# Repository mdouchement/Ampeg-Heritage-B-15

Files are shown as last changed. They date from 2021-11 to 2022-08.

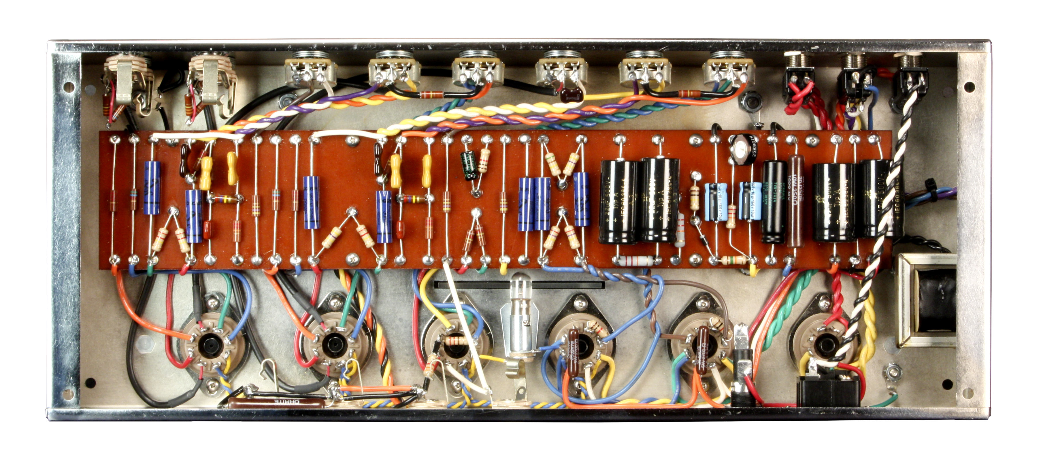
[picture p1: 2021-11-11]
Documents/_Wiring-official.jpg

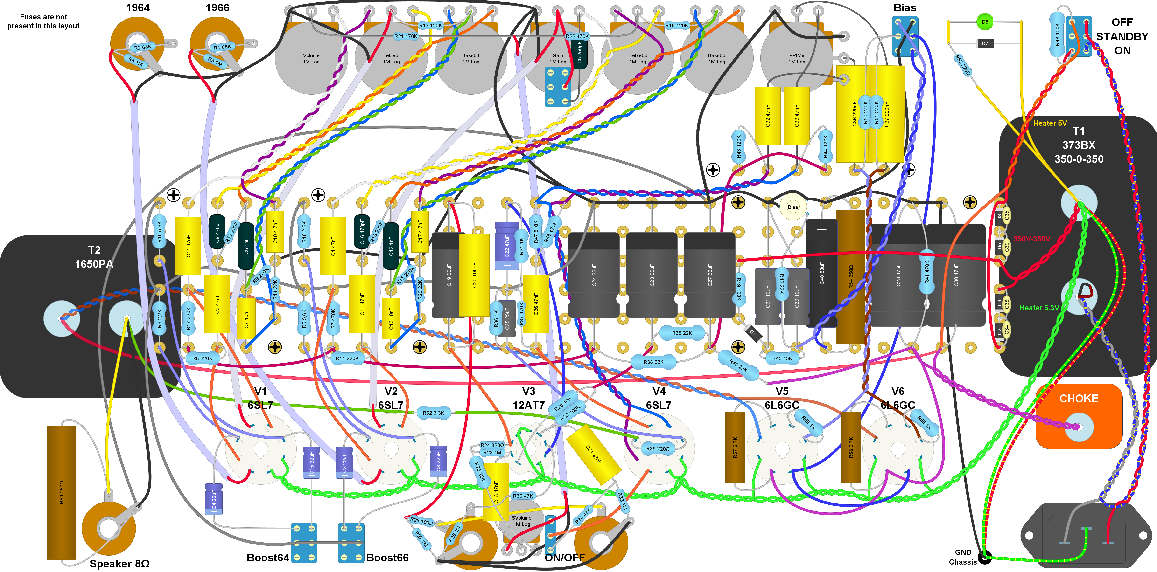
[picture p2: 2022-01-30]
HB15_layout.png

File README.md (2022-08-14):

# Ampeg HB15

This project is a custom modification of the original Ampeg Heritage B15.
You can download the schematic [HB15.pdf](HB15.pdf).

IMG_20220104_171503_nometa

## Warnings

- Use **6L6GC** valves that support 500V at the screen
- Always checks that all capacitors are discharged
  - Even if the 470k 2W resistor shoud discharged the capacitor

## Valves

Valves used in this project:
- TAD - 6L6GCM-STR REDBASE
- Philips USA as JAN 12AT7WC (6201) [NOS military grade]
- JAN 6SL7WGT Philips               [NOS military grade]
- Shuguang 6N9P J level             [NOS military grade]

## Custom mods

- The 100K 2W resistor in parallel with the standby switch reduce all the inrush current which is better for the capacitors
- Boost switches increase the gain of the triode by adding a bypass capactor
- Enable or disable the bright capacitor (boost in 8kHz)
- Effects Loop (buffered) is built to be transparent and you can do severals things around:
  - Enable or disable the effects loop
  - Can be used as a buffered preamp out
  - Can be used as an input for a "preamp in a box"
  - Can be used as distortion stage on the cathode follower by increasing the send volume
    - *Eventually a clean boost of the preamp*
- Post Phase Inverter Master Volume (PPIMV) allowing to push the preamp while keeping the amplifier not too loud
- Negative Feedback loop for rumble fix and different voicing (see schematic)
- Midranges boost is a custom version inpired from Pignose B100V amp
- Adding a 4.7nF capacitor in series with C1 and C3 to cut sub frequencies
  - It may be a side effect by replacing all 22nF by 47nF in order to support a 5 strings bass
  - It also due to the frequency response of my PF-210HE cabinet which have a greater low frequencies response
  - 3.3nF may be better depending your cabinet (and taste)

## Tips

- Use a rubber seal inside the chassis to easily mount a APEM 644 for example
- Use teflon tape and rubber seal to insulate metalic jack plug (e.g. Switchcraft 11) from the chassis to avoid ground loops
- Avoid soldering ground on the potentiometer's cover (gound loops enabler)

## Tools

- [KiCAD](https://kicad.org)
  - https://gitlab.com/kicad/code/kicad
  - https://github.com/KiCad
- [DIYLC](http://diy-fever.com/software/diylc)
  - https://github.com/bancika/diy-layout-creator
- [LiveSPICE](https://github.com/dsharlet/LiveSPICE)
- [Micro-Cap](http://www.spectrum-soft.com/index.shtm)

## Resources

- https://ampeg.com/support/files/Schematics/
- http://www.valvewizard.co.uk/index.html
- https://www.ampbooks.com/mobile/amplifier-calculators
- http://www.guitarscience.net/tsc/info.htm (tonestack calculator)
- https://trioda.com/tools/triode.html (Loadline calculator)

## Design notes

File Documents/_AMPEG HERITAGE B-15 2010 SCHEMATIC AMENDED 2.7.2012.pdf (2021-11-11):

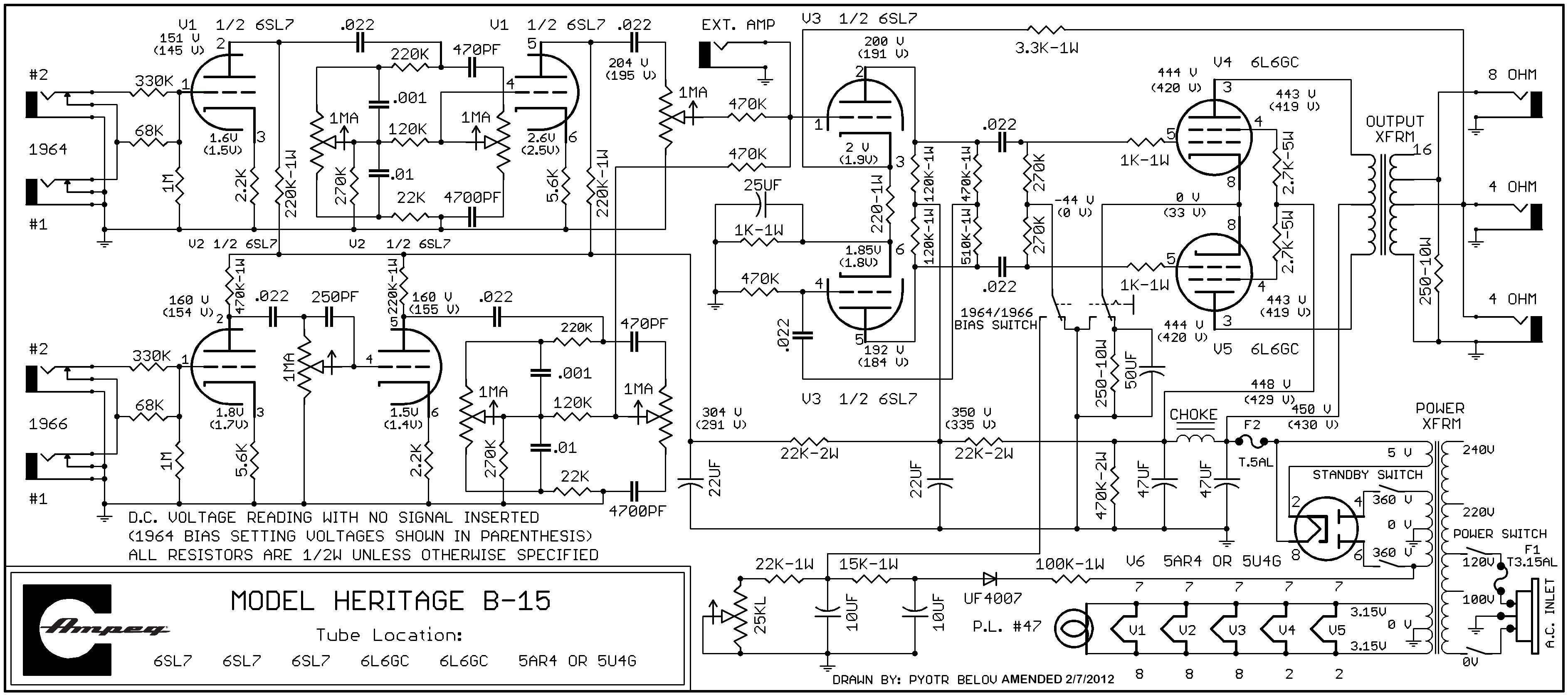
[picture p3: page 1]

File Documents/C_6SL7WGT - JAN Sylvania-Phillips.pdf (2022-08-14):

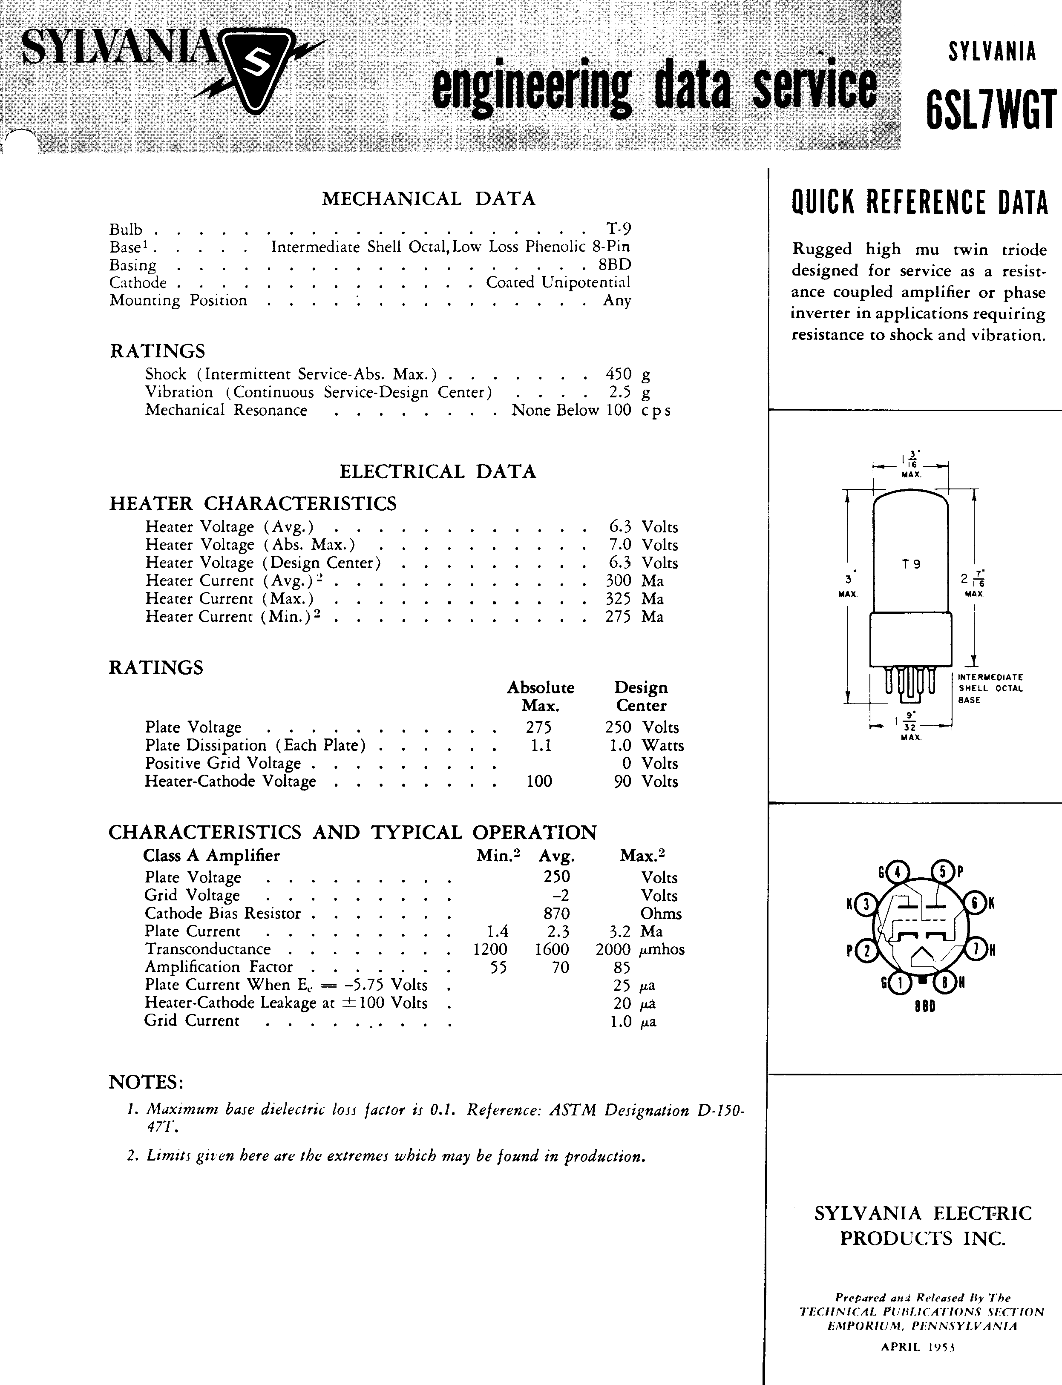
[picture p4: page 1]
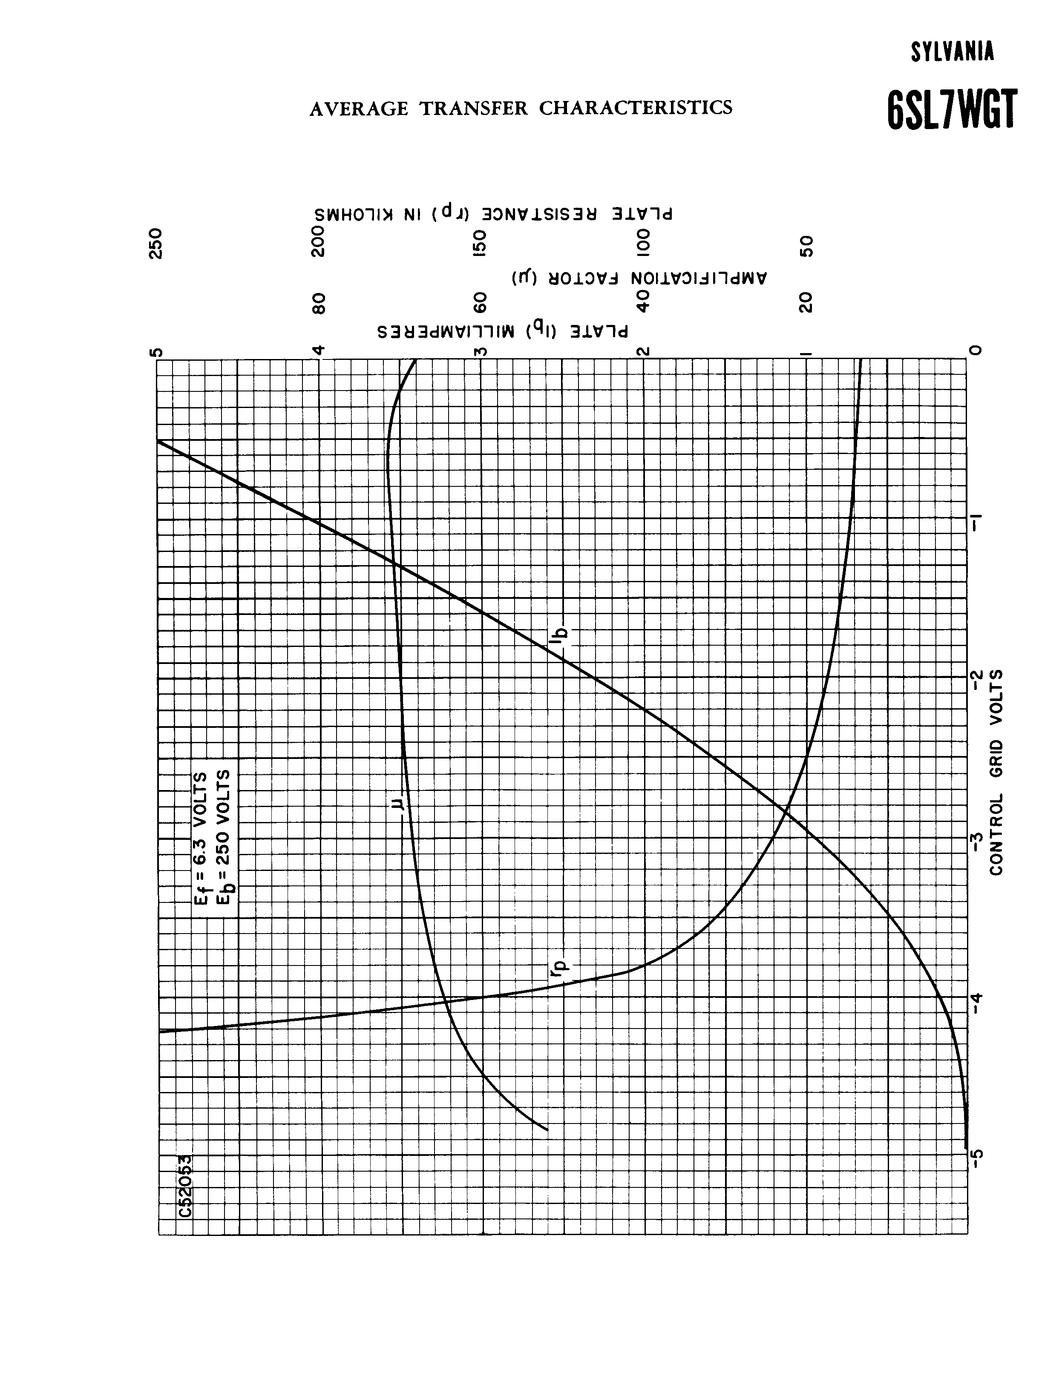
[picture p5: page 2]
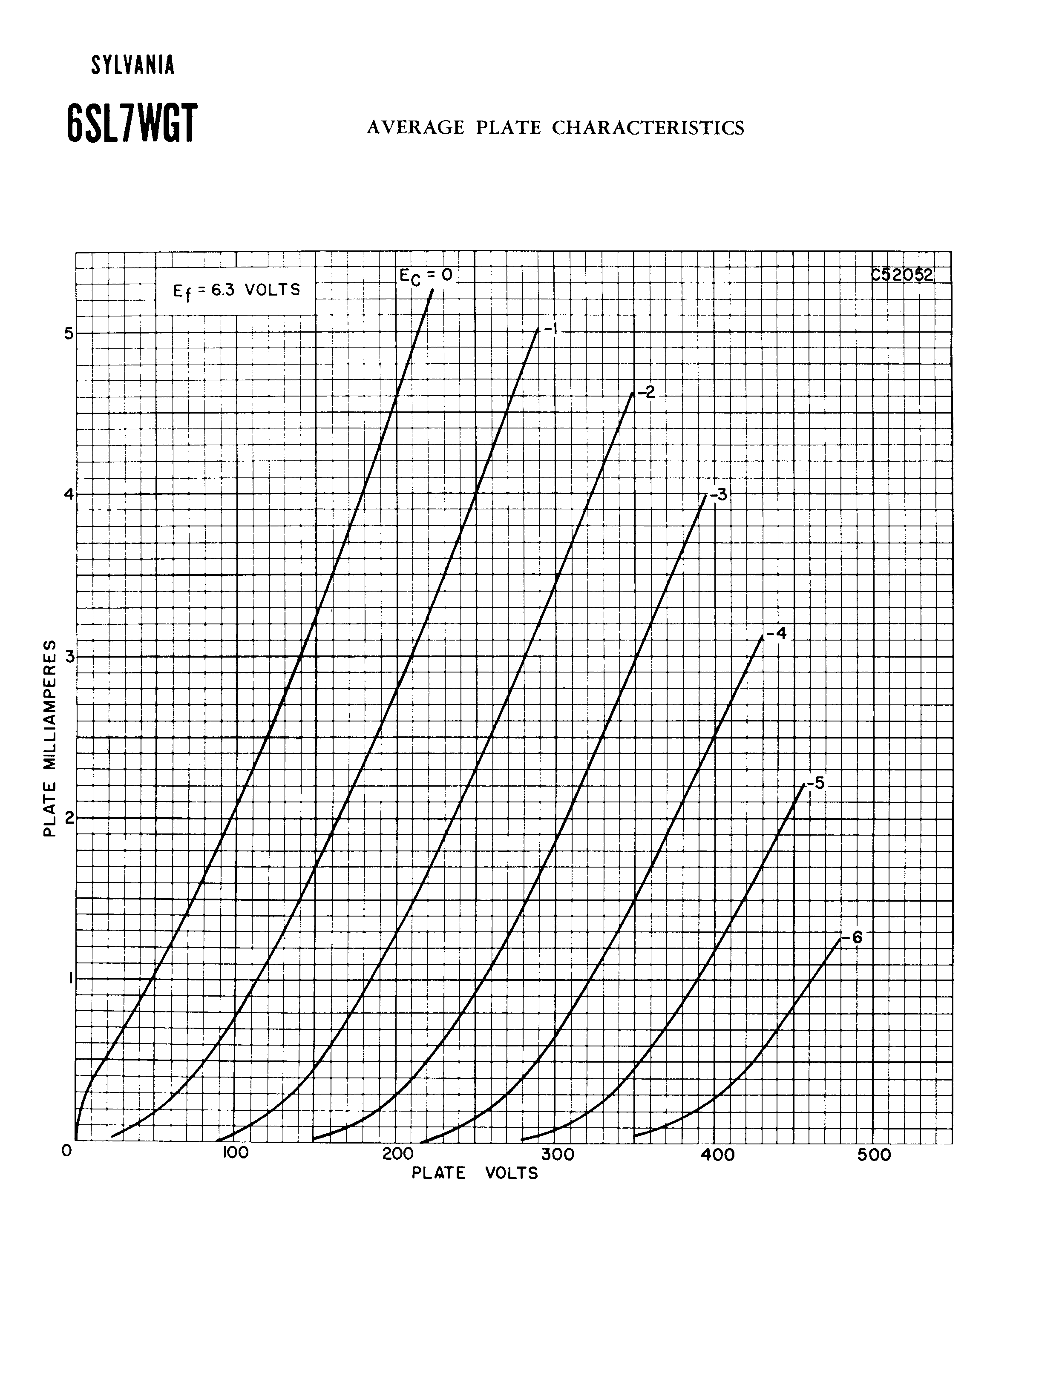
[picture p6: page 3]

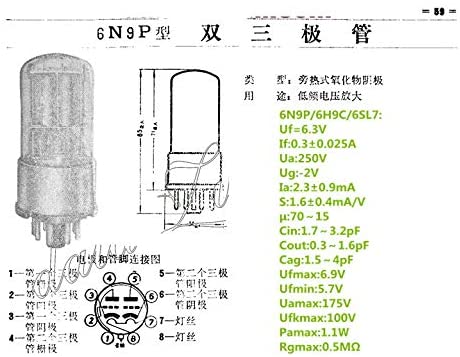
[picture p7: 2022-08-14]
Documents/C_6SL7 - 6N9P-1.jpg

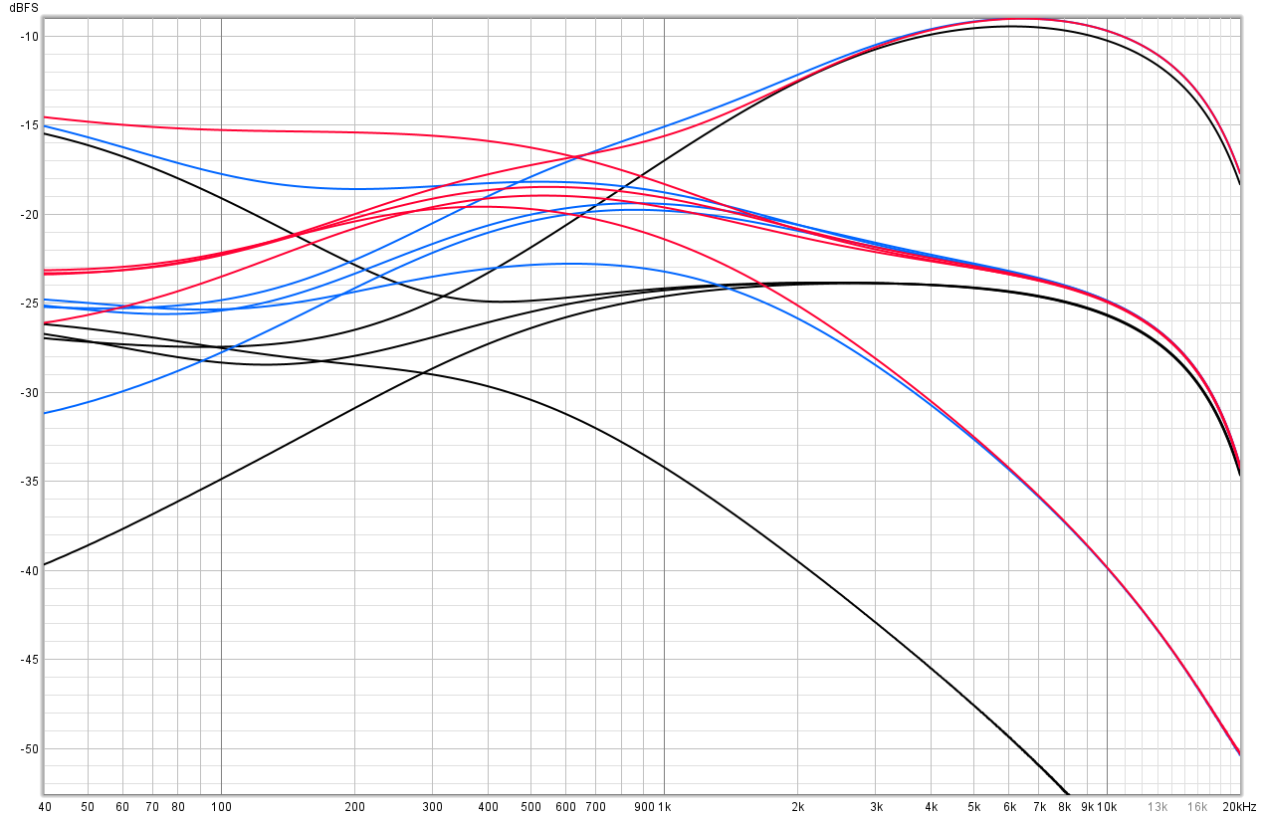
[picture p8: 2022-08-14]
Simulations/1.preamp.EQ.mods.pignose.png

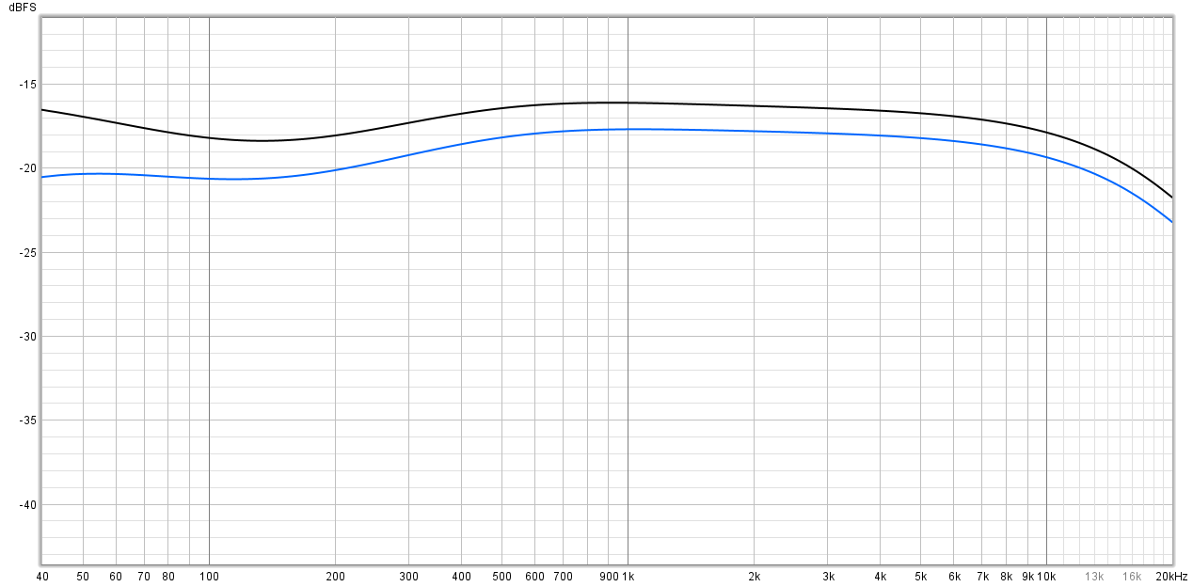
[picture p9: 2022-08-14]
Simulations/1.preamp.EQ.mods.sub_cut.png

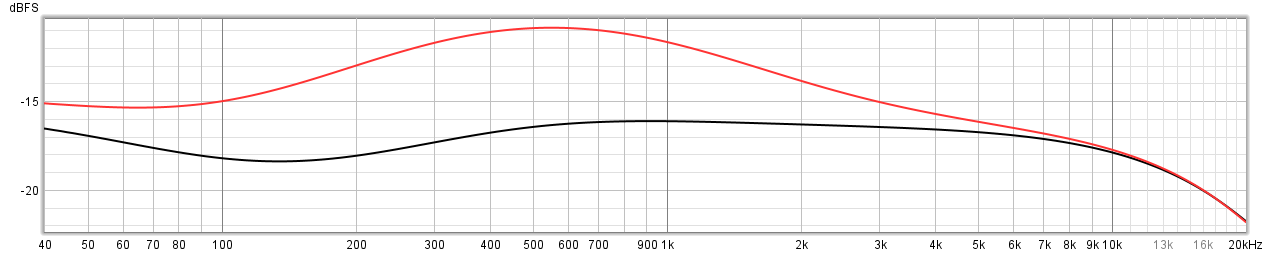
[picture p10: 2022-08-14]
Simulations/1.preamp.EQ.mods.pignose.mid_boost.png

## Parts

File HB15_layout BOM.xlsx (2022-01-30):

Name | Value | Quantity | Ref. | Dealers
Bass64, Bass66, Treble64, Treble66, Volume, SVolume | 1M Log | 5 | Alpha 16mm | Tube-Town | ok
PPIMV | 1M Log Stereo | 1 | Alpha Dual 16mm | Tube-Town | ok
Gain | 1M Log DPDT | 1 | Alpha Push-Pull 16mm | Tube-Town | ok
OFF-STANDBY-ON | DP3T | 1 | APEM 644 H/2 | Tube-Town | ok
Bias | DPDT | 1 | APEM 646 H/2 | Tube-Town | ok
ON/OFF effects loop | SPDT | 1 | Miyama MS-500B | Tube-Town | ok
Boost64, Boost66 | DPDT | 2 | Miyama MS500F | Tube-Town | ok
Bias | 25K Lin | 1 | Miniatur PT15 | Tube-Town | ok
C1, C3, C11, C14, C18, C21, C26, C32, C33 | 47nF 630V | 9 | Illinois Capacitor MPW | Tube-Town | ok
C2, C4, C8, C15 | 22uF 63V | 4 | Nichicon | Retroamplis
C5 | 250pF 500V | 1 | Silver Mica | Tube-Town | ok
C6, C12 | 1nF 500V | 2 | Silver Mica | Tube-Town | ok
C7, C13 | 10nF 630V | 2 | Illinois Capacitor MPW | Tube-Town | ok
C9, C16 | 470pF 500V | 2 | Silver Mica | Mouser
C10, C17 | 4,7nF 630V | 2 | Illinois Capacitor MPW | Tube-Town | ok
C19 | 22uF 350V | 1 | F&T | Tube-Town | ok
C23, C24, C27 | 22uF 500V | 3 | F&T | Tube-Town | ok
C20 | 100nF 630V | 1 | Illinois Capacitor MPW | Tube-Town | ok
C22 | 47uF 63V | 1 | Nichicon | Retroamplis
C25 | 25uF 25V | 1 | Vishay ATOM TVA1205 | Mouser
C28, C30 | 47uF 500V | 2 | F&T | Tube-Town | ok
C29, C31 | 10uF 150V | 2 | Vishay ATOM TVA1406 | Mouser
C34, C35, C38, C39 | 10nF 1KV | 4 | Vishay Ceramic 562R5HKMS10RR | Mouser
C36, C37 | 220nF 630V | 2 | Illinois Capacitor MPW | Tube-Town | ok
C40 | 50uF 150V | 1 | Vishay ATOM TVA1414 | Mouser
CHOKE | 10H 125mA | 1 | Tube-Town TT-CK10 | Tube-Town | ok
Output Transformer | 60W 6600Ω | 1 | Hammond 1650PA | Tube-Town | ok
Power Transformer | 700V 201mA | 1 | Hammond 373BX | Tube-Town | ok
D1, D2, D3, D4, D5 | UF4007 | 5 | UF4007 | Mouser
D6 | OSSV5111A | 1 | OSSV5111A | Retroamplis
D7 | 1N4001 | 1 | 1n4001 | Mouser
In64, In66, Send, Speaker | Jack 6.3mm | 4 | Switchcraft 11 | Tube-Town | ok
Return | Jack 6.3mm | 1 | Switchcraft 12a | Tube-Town | ok
R1, R2 | 68K 0,5W | 2 | Royal OHM metal film | Retroamplis
R39, R53 | 220Ω 1W | 2 | Royal OHM metal film | Retroamplis
R3, R4, R23, R27, R29, R33 | 1M 0,5W | 6 | Royal OHM metal film | Retroamplis
R5, R16 | 5,6K 1W | 2 | Royal OHM metal film | Retroamplis
R6, R10 | 2,2K 1W | 2 | Royal OHM metal film | Retroamplis
R7, R46 | 470K 1W | 2 | Royal OHM metal film | Retroamplis
R8, R11, R17 | 220K 1W | 3 | Royal OHM metal film | Retroamplis
R9, R15 | 270K 0,5W | 2 | Royal OHM metal film | Retroamplis
R12, R18 | 220K 0,5W | 2 | Royal OHM metal film | Retroamplis
R13, R19 | 120K 0,5W | 2 | Royal OHM metal film | Retroamplis
R14, R20 | 22K 0,5W | 2 | Royal OHM metal film | Retroamplis
R21, R22, R37 | 470K 0,5W | 3 | Royal OHM metal film | Retroamplis
R24 | 820Ω 1W | 1 | Royal OHM metal film | Retroamplis
R26 | 10K 1W | 1 | Royal OHM metal film | Retroamplis
R28 | 100Ω 0,5W | 1 | Royal OHM metal film | Retroamplis
R30, R34 | 47K 0,5W | 2 | Royal OHM metal film | Retroamplis
R31, R36, R55, R56 | 1K 1W | 4 | Royal OHM metal film | Retroamplis
R32, R49 | 100K 1W | 2 | Royal OHM metal film | Retroamplis
R35, R38, R40 | 22K 2W | 3 | Royal OHM metal film | Retroamplis
R41 | 470K 2W | 1 | Royal OHM metal film | Retroamplis
R25, R42 | 22K 1W | 2 | Royal OHM metal film | Retroamplis
R43, R44 | 120K 1W | 2 | Royal OHM metal film | Retroamplis
R45 | 15K 1W | 1 | Royal OHM metal film | Retroamplis
R47 | 510K 1W | 1 | Royal OHM metal film | Retroamplis
R48 | 100K 2W | 1 | Royal OHM metal film | Retroamplis
R50, R51 | 270K 1W | 2 | Royal OHM metal film | Retroamplis
R52 | 3,3K 1W | 1 | Royal OHM metal film | Retroamplis
R54, R59 | 250Ω 10W | 2 | Ohmite 20J250E | Mouser
R57, R58 | 2,7K 5W | 2 | Ohmite 25J2K7E | Mouser
Turret Board | 6x30 drills |  | Tube-Town EZ-Board Standard | Tube-Town | ok
Turret Lug | FR4 2mm | 60 | Turret Tube-Town Type 32 | Tube-Town | ok
Turret Board | 1x6 | 1 | Tube-Town EZ-Board 1x6 Turrets | Tube-Town | ok
Octal Socket |  | 5 | Belton VT8 | Tube-Town | ok
Noval Socket |  | 1 | Belton VT9-ST-2 | Tube-Town | ok
V1, V3, V6 | 6SL7 | 3 | NOS selected Shuguang 6N9P J level | TAD
V2 | 12AT7 | 1 | JAN NOS | TAD
V4, V5 | 6L6GC | 2 | TAD 6L6GCm-STR | TAD
Fuseholder |  | 3 |  | Retroamplis
IEC | 230VAC 1A | 1 | IEC Power jack with fuseholder | Tube-Town | ok
Chassis bottom | 1431-26BK3 | 1 | Hammond 1431-26BK3 | Tube-Town | ok
Chassis box | 1441-28BK3 | 1 | Hammond 1441-28BK3 | Tube-Town | ok
Chassis cover | 1451-26BK3 | 1 | Hammond 1451-26BK3 | Tube-Town | ok
Screw choke | M3 x 10 | 2 |  | Tube-Town | ok
Screw IEC | M3 x 10 | 2 |  | Tube-Town | ok
Screw octal socket | M4 x 10 | 10 |  | Tube-Town | ok
Screw noval socket | M3 x 10 | 2 |  | Tube-Town | ok
Screw transformer | M5 x 10 | 8 |  | Tube-Town | ok
Screw turretboard | M2.5 x 10 | 20 | Raised Head Screw | Tube-Town | ok
Screw chassis cover | M4 x 10 | 4 | Socket Head Screw | Tube-Town | ok
Screw chassis bottom |  | 4 | Hammond 1421J6 | Tube-Town | ok
Spacer turretboard | M2.5 x 20 | 10 | Bolt Type 02 | Tube-Town | ok

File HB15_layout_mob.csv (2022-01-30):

Name | Value | Quantity | Notes
Bass64, Bass66, Gain, PPIMV, Treble64, Treble66, Volume, VR1 | 1M Log | 8
Bias, OFF-STANDBY-ON, SW1, SW2, SW3 | DPDT | 5
Bias | 25K Lin | 1
C1, C3, C11, C14, C18, C21, C26, C32, C33 | 47nF 630V | 9
C2, C4, C8, C15 | 22uF 63V | 4
C5 | 250pF 500V | 1
C6, C12 | 1nF 500V | 2
C7, C13 | 10nF 630V | 2
C9, C16 | 470pF 500V | 2
C10, C17 | 4,7nF 630V | 2
C19, C23, C24, C27 | 22uF 500V | 4
C20 | 100nF 630V | 1
C22 | 47uF 63V | 1
C25 | 25uF 25V | 1
C28, C30 | 47uF 500V | 2
C29, C31 | 10uF 150V | 2
C34, C35, C38, C39 | 10nF 1KV | 4
C36, C37 | 220nF 630V | 2
C40 | 50uF 150V | 1
CHOKE, Output Transformer, Power Transformer |  | 3
D1, D2, D3, D4, D5 | UF4007 | 5
D6 | OSSV5111A | 1
D7 | 1N4001 | 1
Eyelet |  | 5
IEC1 |  | 1
J1, J2, J3, J5, Speaker |  | 5
OFF-STANDBY-ON | SPDT | 1
R1, R2 | 68K 0,5W | 2
R1, R2 | 2,7K 5W | 2
R3, R53 | 220Ω 1W | 2
R3, R4, R23, R27, R29, R33 | 1M 0,5W | 6
R5, R16 | 5,6K 1W | 2
R6, R10 | 2,2K 1W | 2
R7, R37, R46 | 470K 1W | 3
R8, R11, R17 | 220K 1W | 3
R9, R18 | 270K 0,5W | 2
R12, R18 | 220K 0,5W | 2
R13, R19 | 120K 0,5W | 2
R14, R20, R25 | 22K 0,5W | 3
R21, R22 | 470K 0,5W | 2
R24 | 820Ω 0,5W | 1
R26 | 10K 1W | 1
R28 | 100Ω 0,5W | 1
R30, R34 | 47K 0,5W | 2
R31, R36, R55, R56 | 1K 1W | 4
R32, R49 | 100K 1W | 2
R35, R38, R40 | 22K 2W | 3
R41 | 470K 2W | 1
R42 | 22K 1W | 1
R43, R44 | 120K 1W | 2
R45 | 15K 1W | 1
R47 | 510K 1W | 1
R48 | 100K 2W | 1
R50, R51 | 270K 1W | 2
R52 | 3,3K 1W | 1
R54, R59 | 250Ω 10W | 2
SVolume | 50K Log | 1
Turret Lug |  | 186
V1, V3, V6 | 6SL7 | 3
V2 | 12AT7 | 1
V4, V5 | 6L6GC | 2

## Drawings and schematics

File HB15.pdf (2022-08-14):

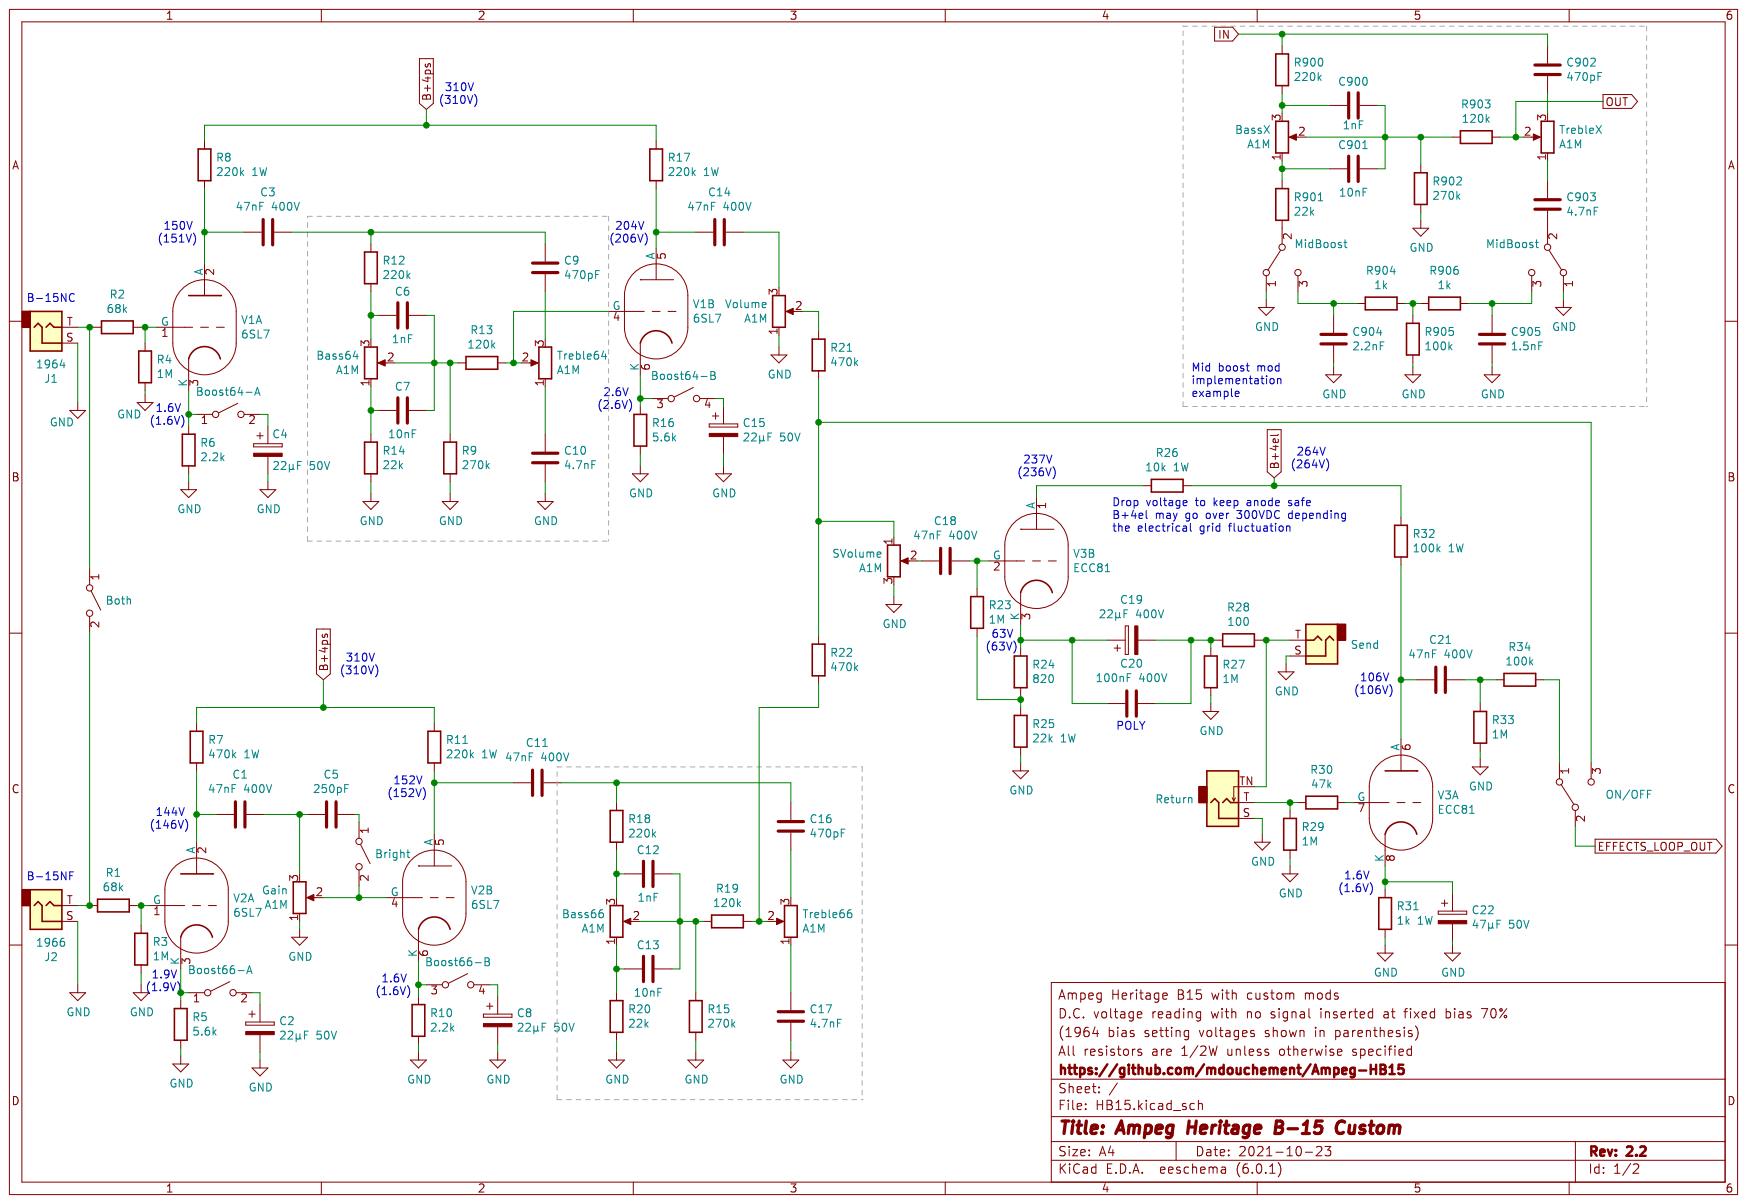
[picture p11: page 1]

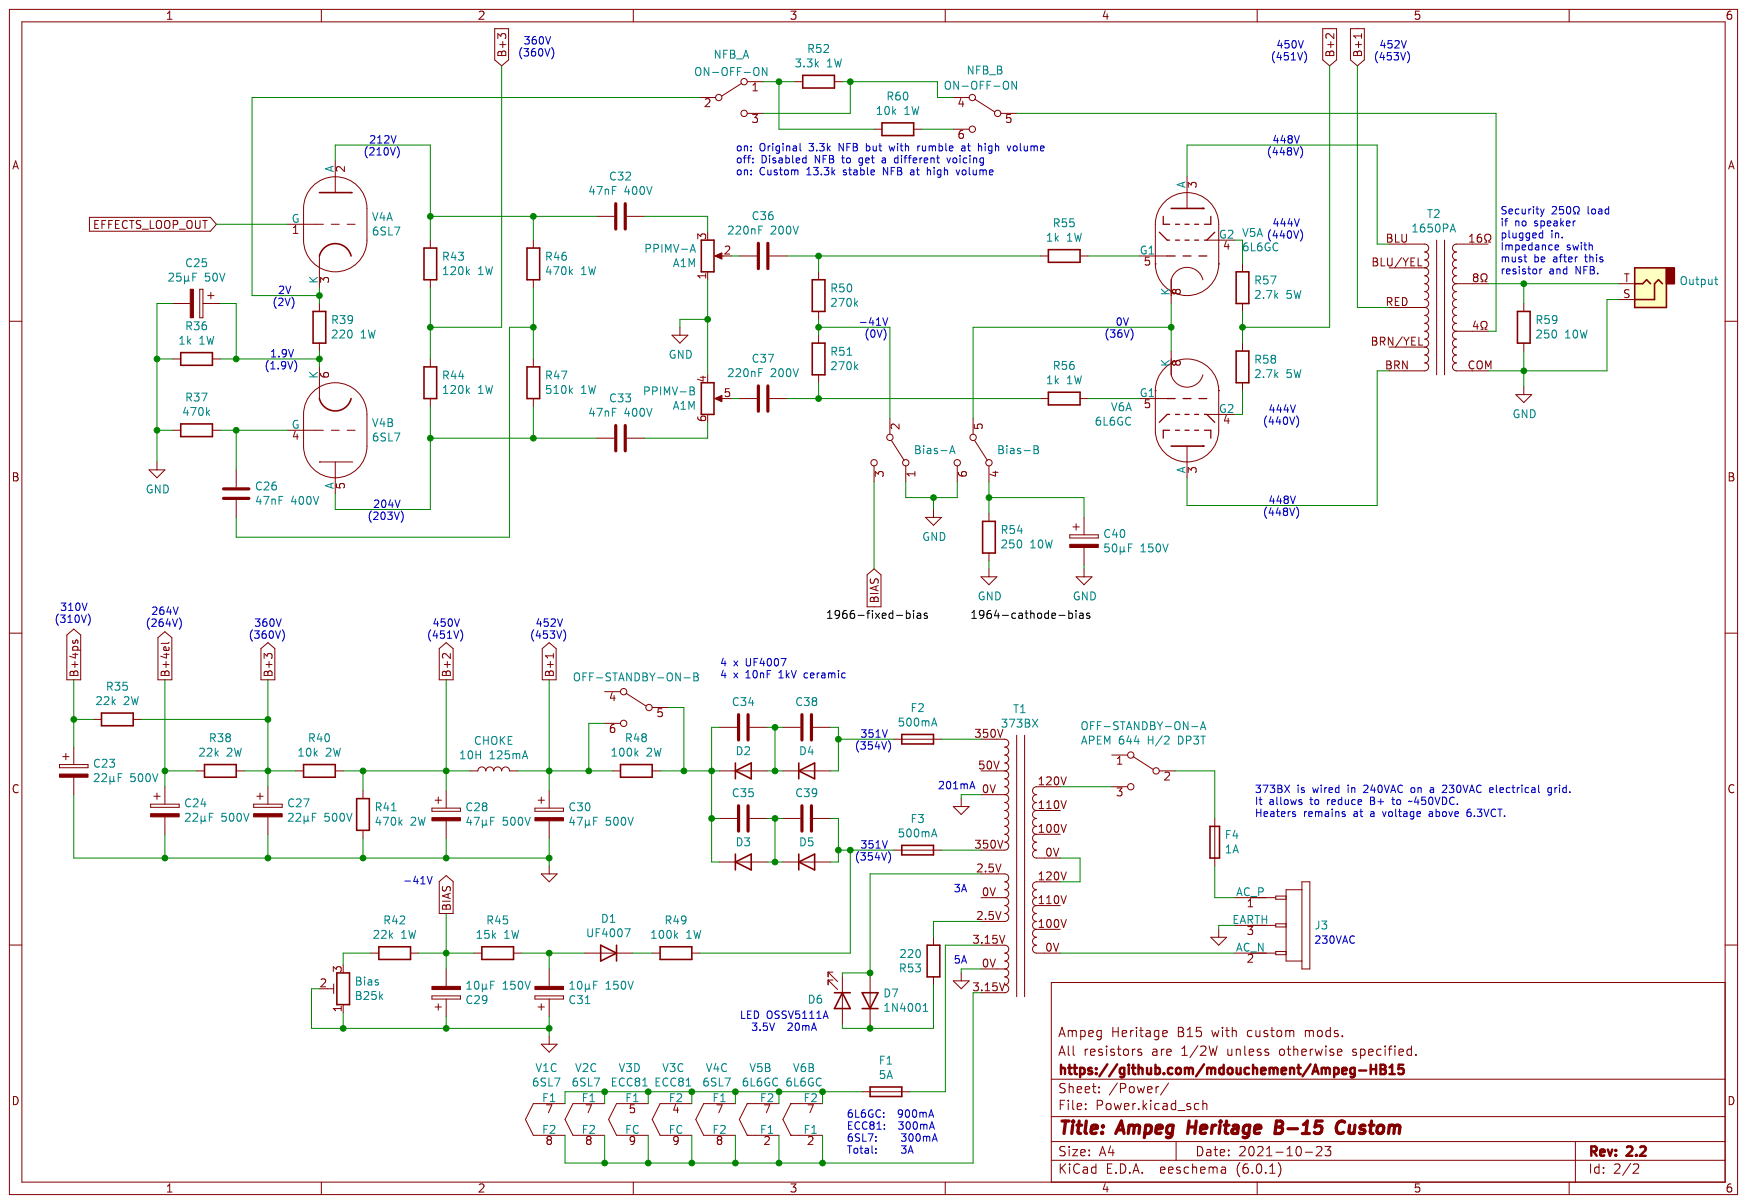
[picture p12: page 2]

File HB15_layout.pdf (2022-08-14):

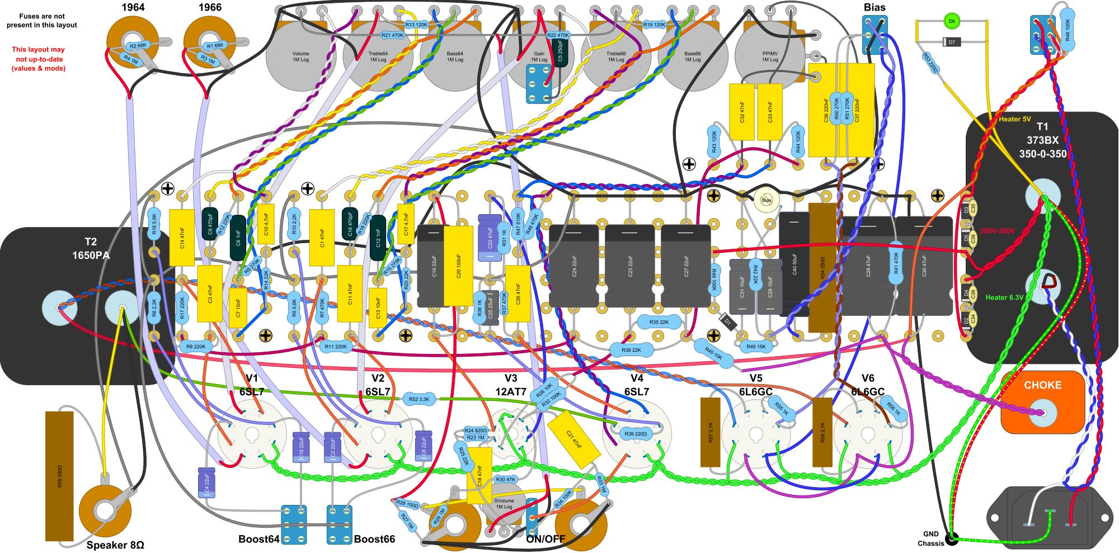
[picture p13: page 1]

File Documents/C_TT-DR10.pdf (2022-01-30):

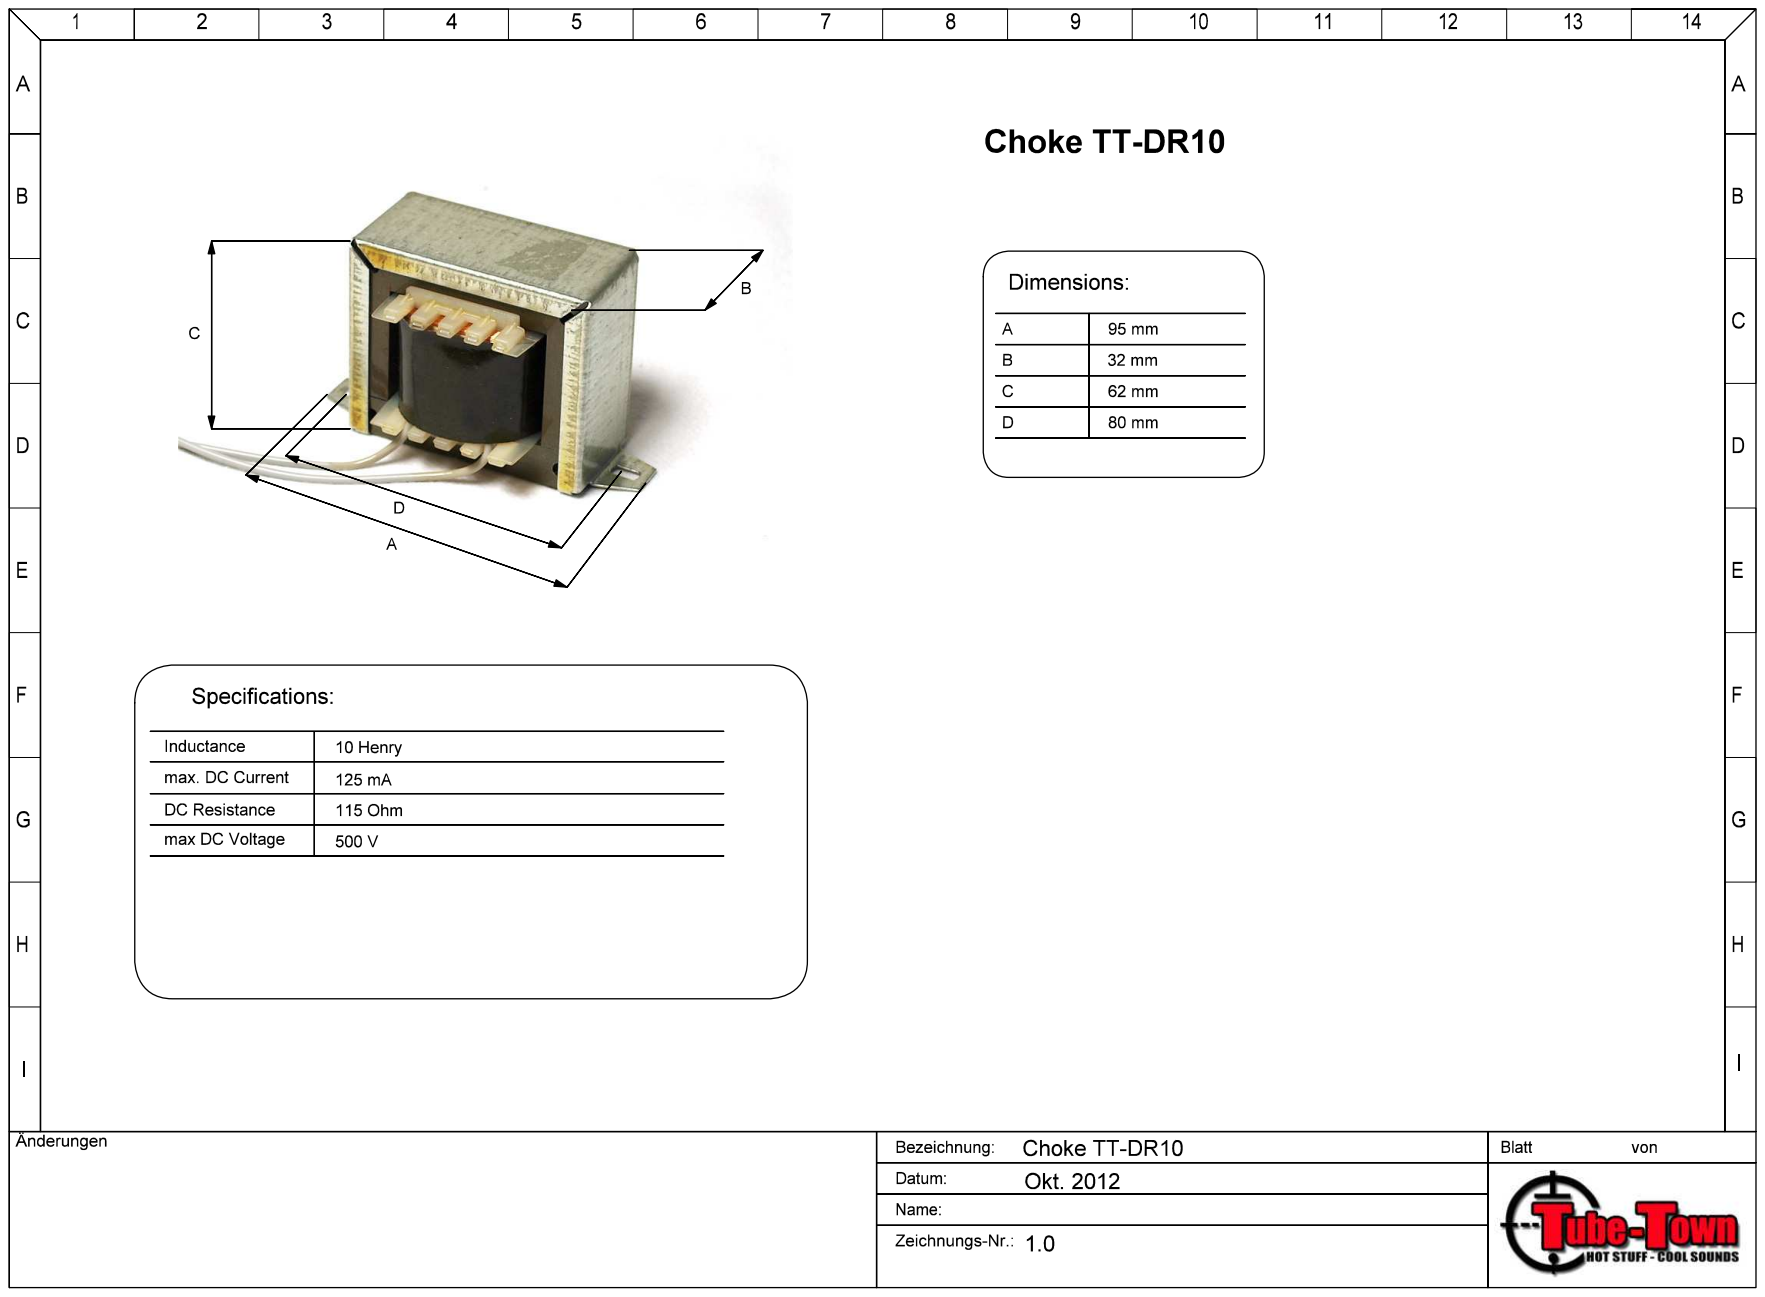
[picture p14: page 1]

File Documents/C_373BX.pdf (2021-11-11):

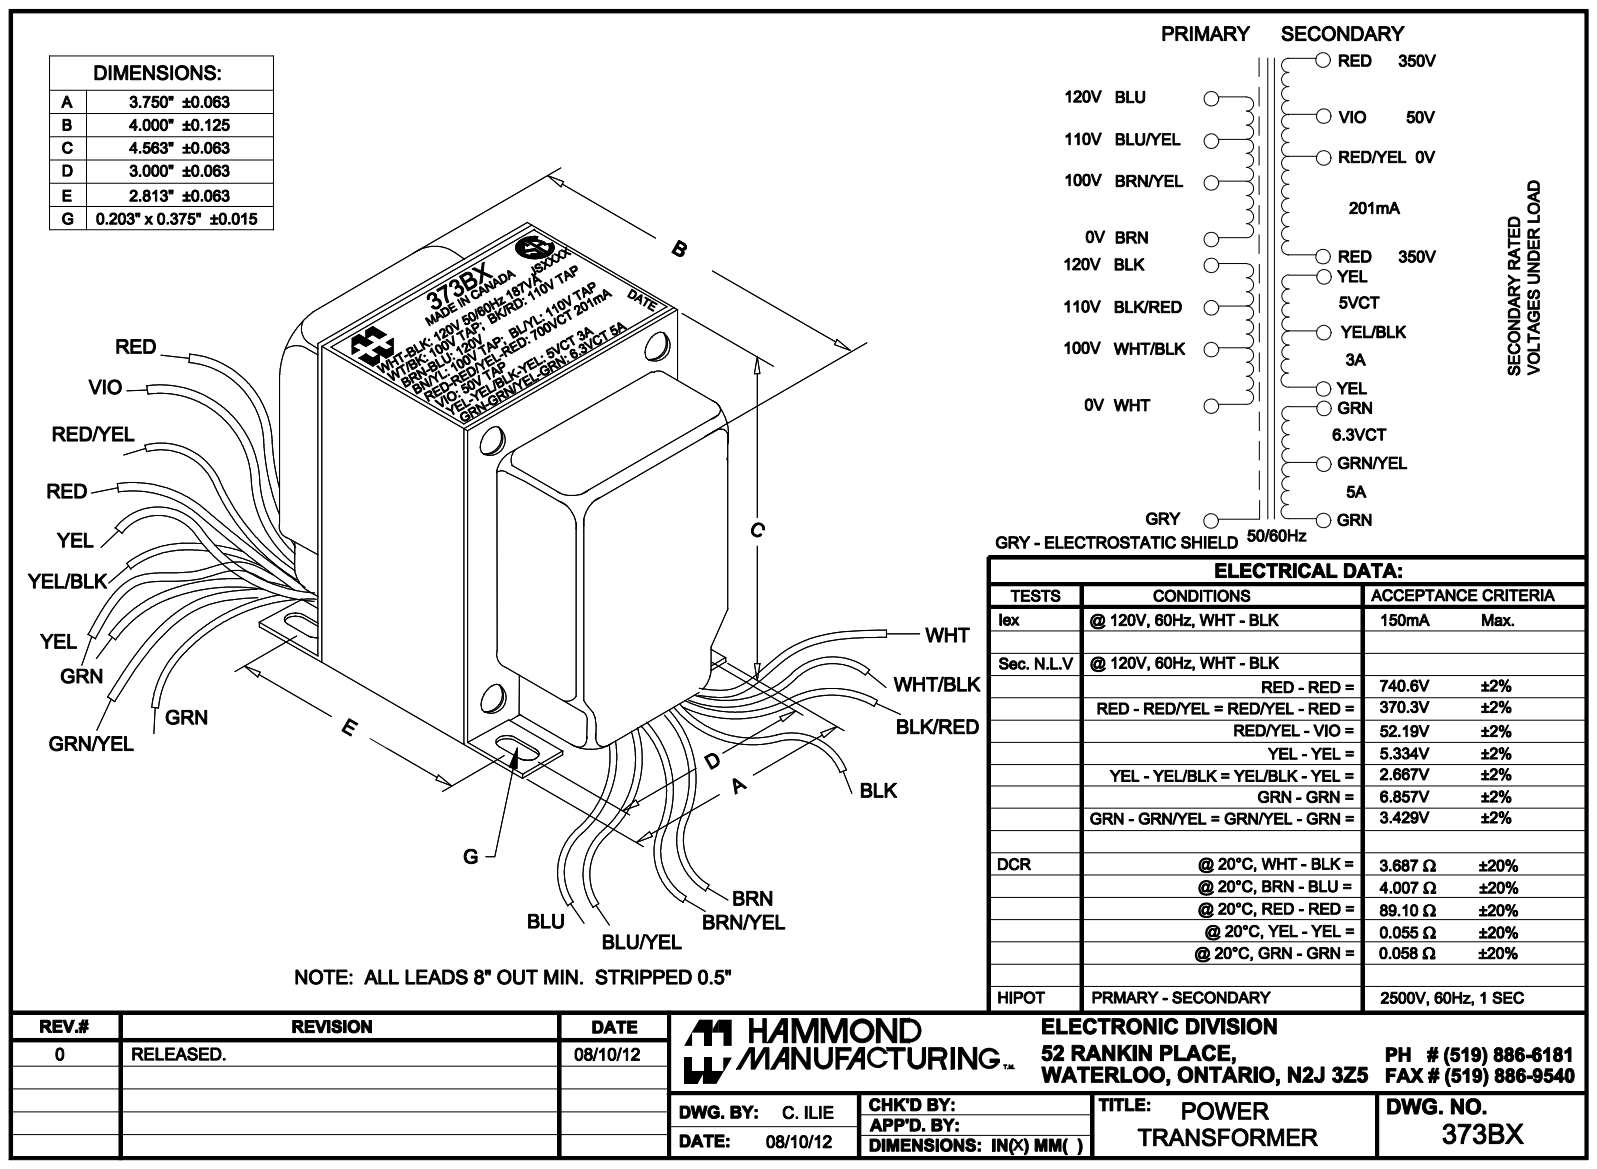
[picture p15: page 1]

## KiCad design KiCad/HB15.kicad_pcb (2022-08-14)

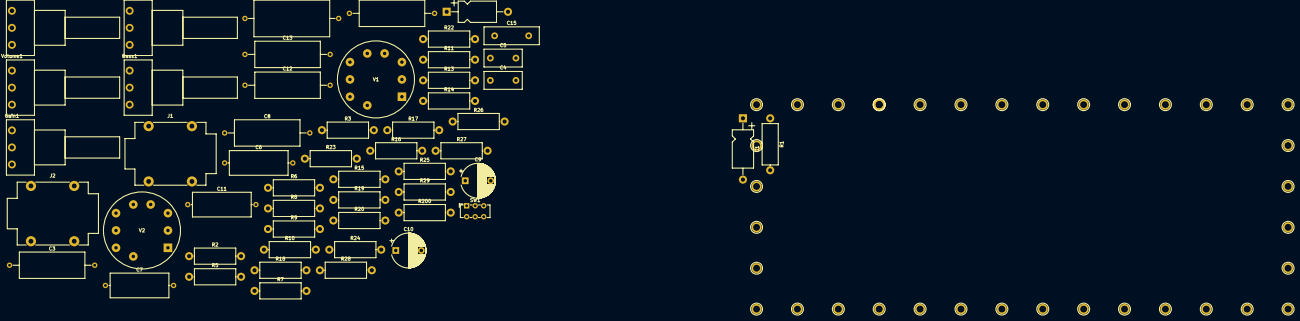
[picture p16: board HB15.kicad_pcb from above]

Board: 2 copper layers, 53 parts (0 on the bottom side), 37 nets, no tracks yet.

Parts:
Bass1: B250K; Potentiometer_Piher_PC-16_Single_Horizontal
C1, C2: 22µF 50V; CP_Axial_L11.0mm_D6.0mm_P18.00mm_Horizontal
C3, C8, C12, C13: 100nF 400V; C_Axial_L19.0mm_D7.5mm_P25.00mm_Horizontal
C4: 47pF 1KV; C_Disc_D11.0mm_W5.0mm_P7.50mm
C5: 150pF; C_Disc_D11.0mm_W5.0mm_P7.50mm
C6, C7, C11: 47nF; C_Axial_L17.0mm_D7.0mm_P20.00mm_Horizontal
C9, C10: 10µF 250V; CP_Radial_D10.0mm_P7.50mm
C14: 220nF 400V; C_Axial_L22.0mm_D10.5mm_P27.50mm_Horizontal
C15: 1nF; C_Disc_D16.0mm_W5.0mm_P10.00mm
C200: 100nF; C_Axial_L19.0mm_D7.5mm_P25.00mm_Horizontal
Gain1: A250K; Potentiometer_Piher_PC-16_Single_Horizontal
J1: Line in; Jack_6.35mm_Neutrik_NMJ4HCD2_Horizontal
J2: Line out; Jack_6.35mm_Neutrik_NMJ4HCD2_Horizontal
Midrange1: B25K; Potentiometer_Piher_PC-16_Single_Horizontal
R1, R2, R19: 1.5K 0.5W; R_Axial_DIN0414_L11.9mm_D4.5mm_P15.24mm_Horizontal
R3, R11, R20: 100K 1W; R_Axial_DIN0414_L11.9mm_D4.5mm_P15.24mm_Horizontal
R5, R15: 68K; R_Axial_DIN0414_L11.9mm_D4.5mm_P15.24mm_Horizontal
R6: 220K; R_Axial_DIN0414_L11.9mm_D4.5mm_P15.24mm_Horizontal
R7, R13, R18, R25, R200: 1M; R_Axial_DIN0414_L11.9mm_D4.5mm_P15.24mm_Horizontal
R8, R10, R23, R28: 470K; R_Axial_DIN0414_L11.9mm_D4.5mm_P15.24mm_Horizontal
R9, R17, R22, R24, R27: 100K; R_Axial_DIN0414_L11.9mm_D4.5mm_P15.24mm_Horizontal
R14: 47K; R_Axial_DIN0414_L11.9mm_D4.5mm_P15.24mm_Horizontal
R16: 10K 1W; R_Axial_DIN0414_L11.9mm_D4.5mm_P15.24mm_Horizontal
R26: 1.5K; R_Axial_DIN0414_L11.9mm_D4.5mm_P15.24mm_Horizontal
R29: 10K; R_Axial_DIN0414_L11.9mm_D4.5mm_P15.24mm_Horizontal
SW1: On/Bypass; SW_E-Switch_EG1271_DPDT
Treble1: B250K; Potentiometer_Piher_PC-16_Single_Horizontal
V1, V2: ECC83; Valve_Noval_P
Volume1: A250K; Potentiometer_Piher_PC-16_Single_Horizontal

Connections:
GND: C1.2, C2.2, C9.2, C10.2, C15.2, Gain1.1, J1.T, J2.T, Midrange1.1, R1.2, R2.2, R7.2, R8.2, R10.2, R13.2, R18.2, R19.2, R23.2, R27.2, R28.2, R200.2, Volume1.1
unnamed: Bass1.1, C7.1, Midrange1.2, Midrange1.3
unnamed: Bass1.2, Bass1.3, C6.1, Treble1.1
unnamed: C1.1, C4.2, R1.1, V1.3
unnamed: C2.1, R2.1, V1.8
unnamed: C3.1, R6.1
unnamed: C3.2, R3.2, V1.1
unnamed: C4.1, R5.1, R7.1, V1.2
unnamed: C5.1, Treble1.3
unnamed: C5.2, R14.2, R15.1
unnamed: C6.2, C7.2, R15.2
unnamed: C8.1, R13.1, R14.1
unnamed: C8.2, R11.2, V1.6
unnamed: C9.1, R3.1, R11.1, R16.1
unnamed: C11.1, R17.1
unnamed: C11.2, Treble1.2
unnamed: C12.1, R22.1
unnamed: C12.2, R20.2, V2.1
unnamed: C13.1, R24.1
unnamed: C13.2, Volume1.2
unnamed: C14.1, R28.1, R29.1
unnamed: C14.2, R26.1, V2.8
unnamed: C15.1, R29.2, SW1.6
unnamed: C200.1, R5.2
unnamed: C200.2, R200.1, SW1.3
unnamed: Gain1.2, R9.1
unnamed: Gain1.3, R6.2, R8.1
unnamed: J1.S, SW1.2
unnamed: J2.S, SW1.5
unnamed: R9.2, R10.1, V1.7
unnamed: R17.2, R18.1, V2.2
unnamed: R19.1, V2.3
unnamed: R22.2, R23.1, Volume1.3
unnamed: R24.2, R25.1, V2.7
unnamed: R25.2, R26.2, R27.1
unnamed: SW1.1, SW1.4
VCC: C10.1, R16.2, R20.1, V2.6

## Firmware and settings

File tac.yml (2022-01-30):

#
# https://github.com/mdouchement/tac
#
voltage: 350-0-350 # Or just `0-350' for non center tap transformer
current: 0.201
rectifier: DIODE # DIODE (full wave), GZ34, EZ81, 5U4B, 5Y3
choke:
  inclue_screen: true
  capacitor: 0.000047 # 47µF for first PSU capacitor (use 0 to not compute choke)
power_valves:
  number_of_valves: 2
  model: 6L6GC # EL34, 6L6GC, 6V6S
  topology: PP # SE, PP
  rload: 6600 # Output transformer primary impedance
preamp_valves:
- model: ECC81 # ECC81, ECC83S, ECC803S, 6SL7
  number_of_triodes: 2
- model: 6SL7
  number_of_triodes: 6
cathode_bypass_capacitors:
- 1000.0
- 2200.0
- 5600.0
led_resistor:
  # Model OSSV5111A
  # https://shop.strato.com/WebRoot/StoreES2/Shops/62070367/MediaGallery/Datasheets/LED_5_UV_WCLEAR.pdf
  vac: 5.33 # Rectifier AC voltage
  dc_forward_voltage: 3.5
  current: 0.02
